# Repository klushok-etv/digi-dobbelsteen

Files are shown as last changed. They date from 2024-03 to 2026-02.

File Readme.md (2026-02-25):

# Digi Dobbelsteen

Digi Dobbelsteen is a digital dice project based on the attiny85 that uses 7 LEDs and a push button.

## Features

- 7 LEDs to display the result of the dice roll
- A push button to roll the dice
- A vibration sensor to roll the dice when the device is shaken

## Usage

The code was written in PlatformIO, so you can use that to compile and upload the code to the attiny85.

The schematic was made in KiCad 7.0, so you can use that to open the schematic and PCB files.

## Schematic

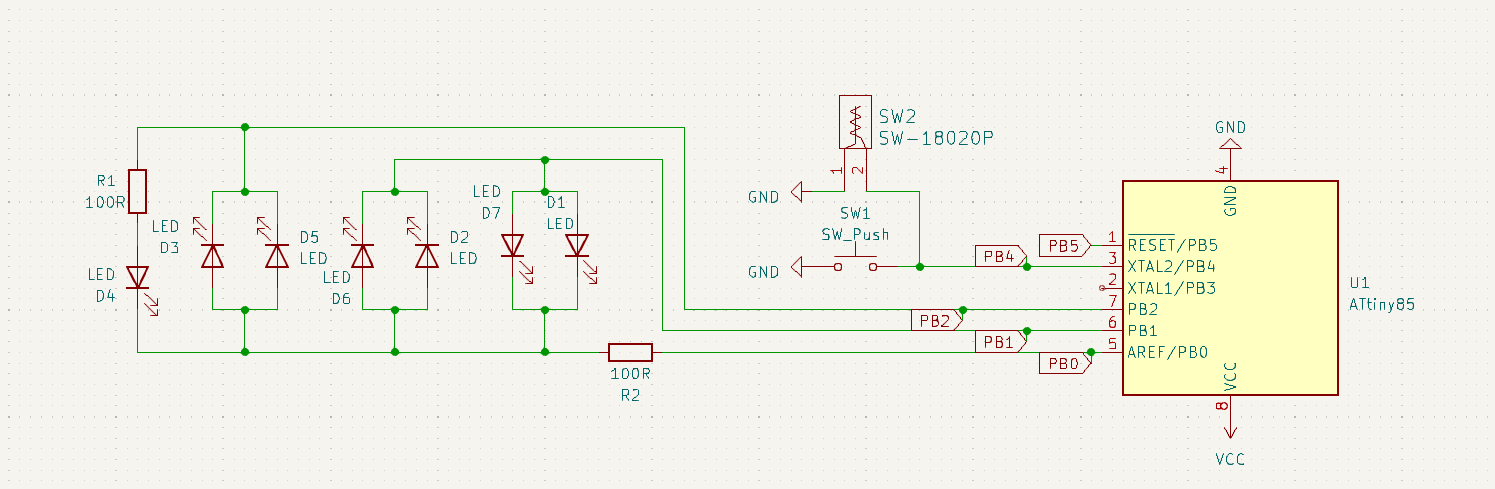
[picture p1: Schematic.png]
Schematic width=100px


## Charlieplexing

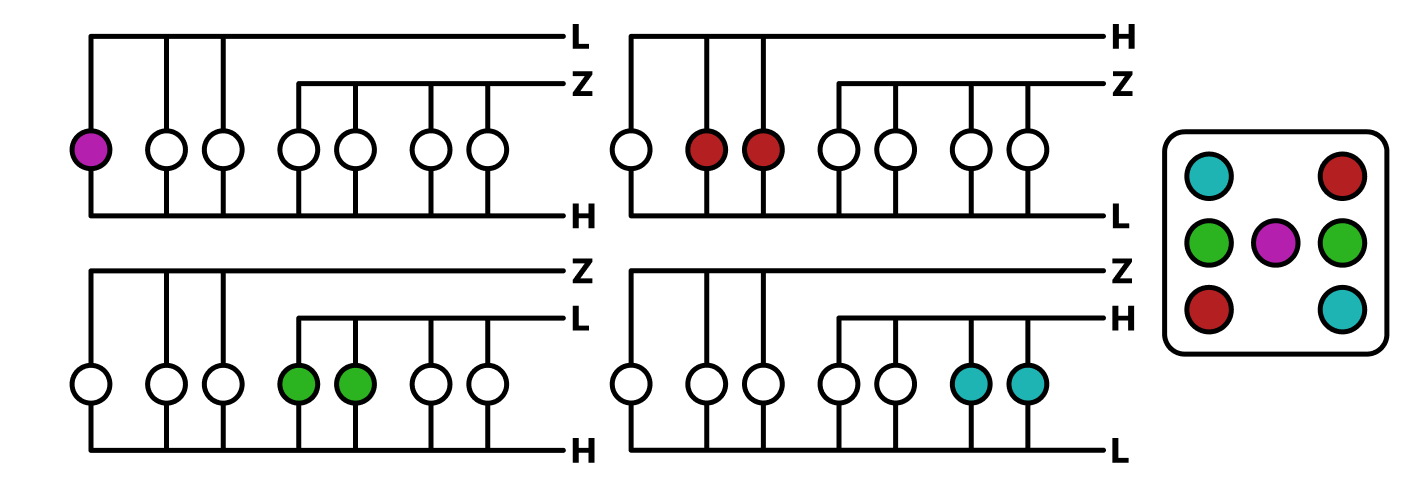
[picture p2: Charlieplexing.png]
Charlieplexing


## PCB

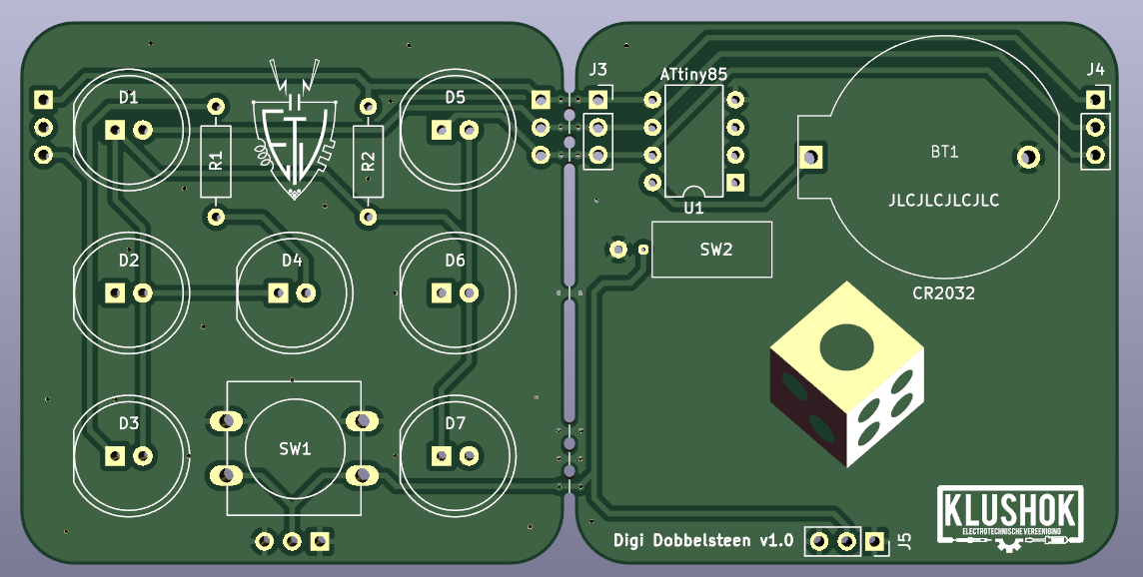
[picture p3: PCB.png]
PCB


## Programing

A precompiled binary is available for the attiny13 under releases. Upload to the chip using the following command:

```console
avrdude -p attiny13 -c usbasp-clone -B 100kHz -e -U flash:w:t13dobbelsteen.elf -U lfuse:w:t13dobbelsteen.elf -U hfuse:w:t13dobbelsteen.elf -U eeprom:w:t13dobbelsteen.elf -U lock:w:t13dobbelsteen.elf
```

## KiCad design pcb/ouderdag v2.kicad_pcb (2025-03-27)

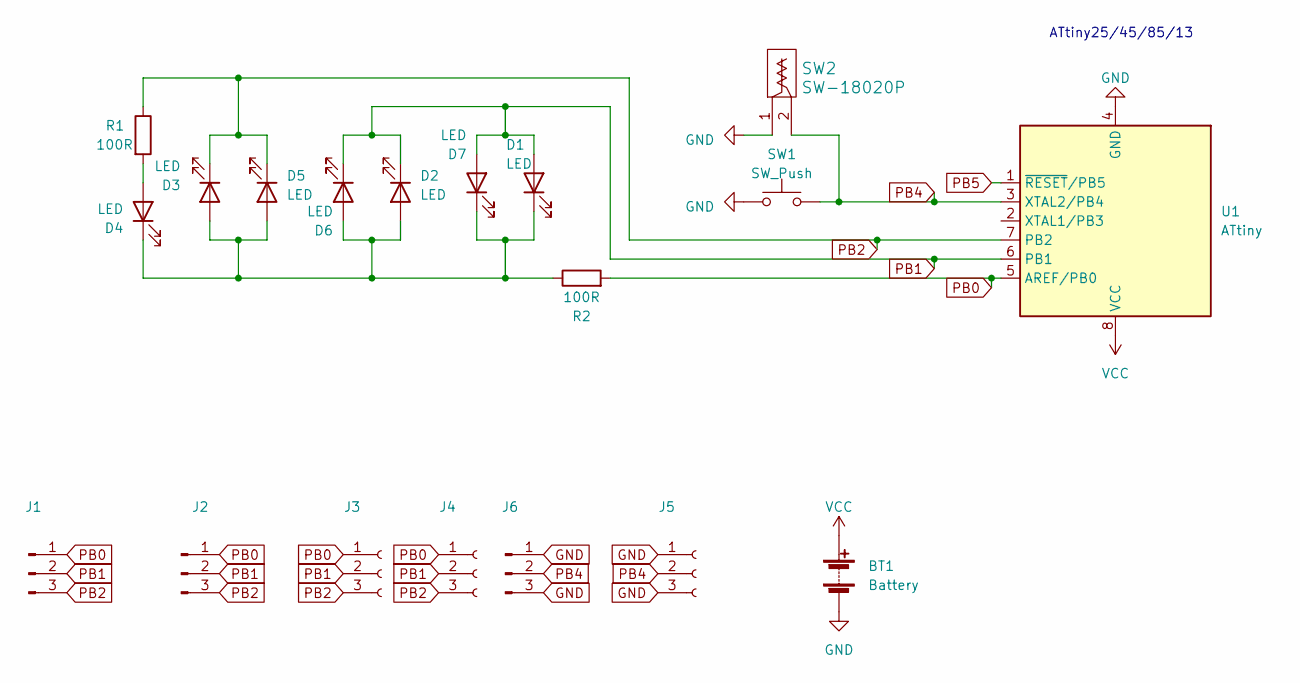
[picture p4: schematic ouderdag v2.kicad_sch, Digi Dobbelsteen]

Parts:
BT1: Battery; cr2032
D1, D2, D3, D4, D5, D6, D7: LED; LED_D10.0mm
J1, J2, J6: Conn_01x03_Pin; PinHeader_1x03_P2.54mm_Vertical
J3, J4, J5: Conn_01x03_Socket; PinSocket_1x03_P2.54mm_Vertical
R1, R2: 100R; R_Axial_DIN0207_L6.3mm_D2.5mm_P10.16mm_Horizontal
SW1: SW_Push; SW_PUSH-12mm
SW2: SW-18020P
U1: ATtiny; DIP-8_W7.62mm

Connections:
GND: BT1.2 (-), J5.1, J5.3, J6.1, J6.3, SW1.1, SW2.1, U1.4 (GND)
unnamed: D1.1 (K), D2.2 (A), D3.2 (A), D4.1 (K), D5.2 (A), D6.2 (A), D7.1 (K), R2.1
unnamed: D4.2 (A), R1.2
PB0: J1.1, J2.1, J3.1, J4.1, R2.2, U1.5 (AREF/PB0)
PB1: D1.2 (A), D2.1 (K), D6.1 (K), D7.2 (A), J1.2, J2.2, J3.2, J4.2, U1.6 (PB1)
PB2: D3.1 (K), D5.1 (K), J1.3, J2.3, J3.3, J4.3, R1.1, U1.7 (PB2)
PB4: J5.2, J6.2, SW1.2, SW2.2, U1.3 (XTAL2/PB4)
PB5: U1.1 (~RESET/PB5)
VCC: BT1.1 (+), U1.8 (VCC)

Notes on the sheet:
ATtiny25/45/85/13

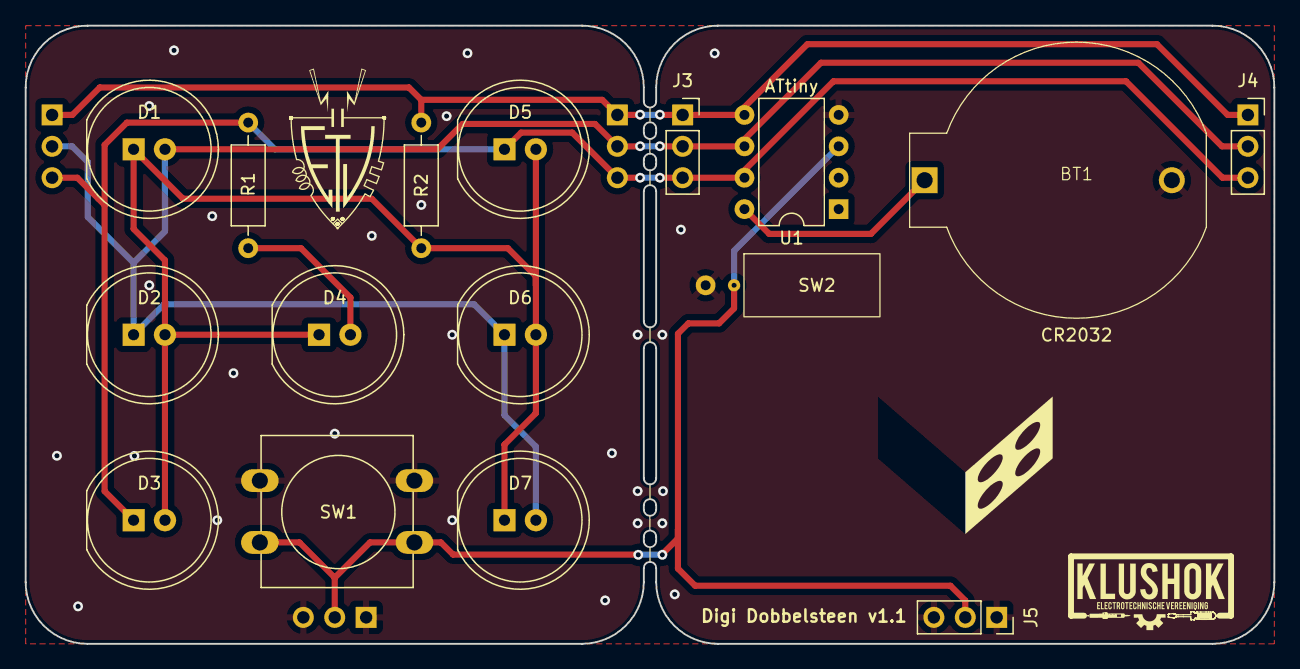
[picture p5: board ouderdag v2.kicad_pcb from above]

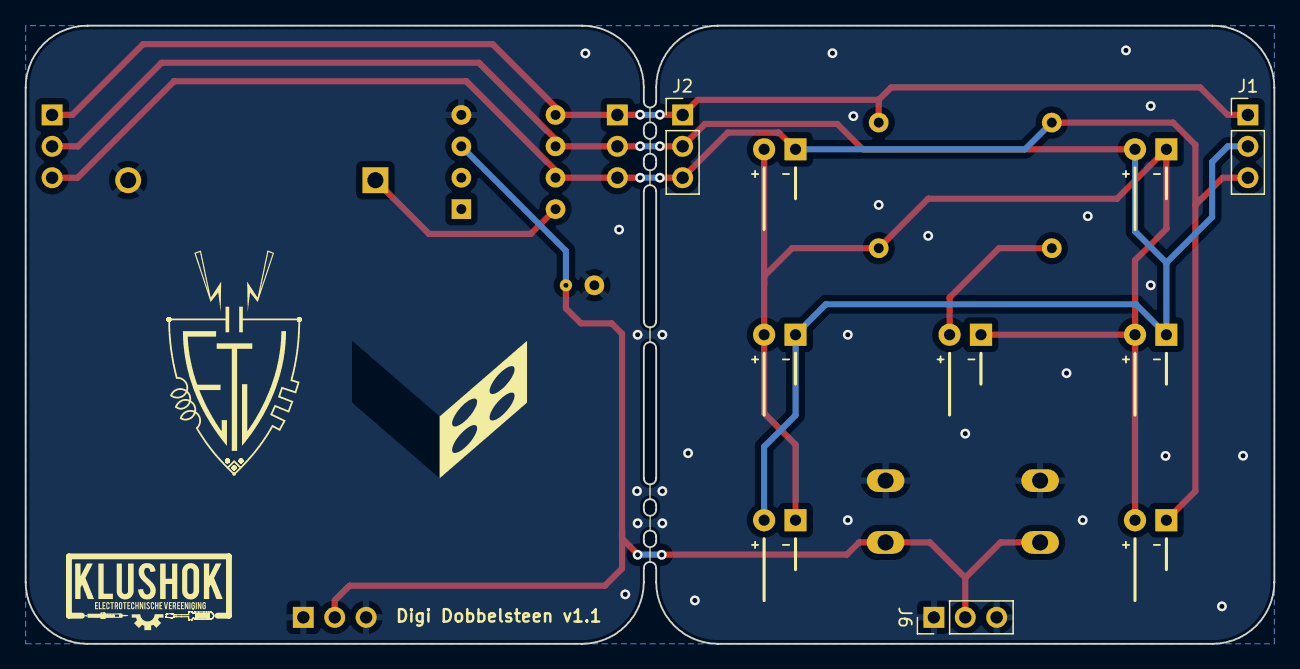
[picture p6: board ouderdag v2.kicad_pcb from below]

Board: 2 copper layers, 101.0 x 50.0 mm, 21 parts (4 on the bottom side), 8 nets.

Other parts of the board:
Ref**: Val**; Art
Ref**#2: Val**; Art

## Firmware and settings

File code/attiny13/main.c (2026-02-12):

/* Attiny Dice v1 using t13
   Jeremy de Waal - Electrotechnische Vereeniging - 2025
   sub 1k binary developed for use with attiny13
   Feature compatible with version from Ryan Kolk
*/

#include <avr/io.h>
#include <util/delay.h>
#include <avr/interrupt.h>
#include <avr/sleep.h>
#include <stdlib.h>
#include <avr/power.h>

/* function definitions */
uint8_t randomDieRoll();
void rngUpdate();
void auxRngUpdate();
void goToSleep ();
void displayRandomNumber();
void roll();
void setDelayLeft(uint16_t newDelay);
void myDelay(uint16_t delay);


/* Global Variables */
uint16_t rngState = 120;
uint8_t auxRngState = 4; // (VO)
enum CharlieState {STATE0, STATE1, STATE2};
enum CharlieState volatile charlieSlot = STATE0;
uint8_t ledOn, ledOff;
uint8_t const ledNumber[6] = {0b00000001, 0b00000010, 0b00000011, 0b00001010, 0b00001011, 0b00001110}; // lookup table
uint8_t volatile length, progress;
uint16_t volatile delayLeft;


int main(void)
{
    TCCR0B = (0 << CS02 | 0 << CS01 | 1 << CS00); // Timer/Counter0 run without prescaler
    TIMSK0 = (1 << TOIE0); // Timer/Counter0 Overflow Interrupt Enable
    PCMSK = (1 << PCINT4); // mask pin change interupt 4
    GIMSK = (1 << PCIE); // Pin Change Interrupt Enable
    sei(); // global interrupt enable
    while(1)
    {
        int16_t delayTime;
        roll(); // update global variables progress, length
        do // The animation part
        {
            displayRandomNumber();
            progress += 1;
            delayTime = 50 + (350 * progress / length); // could save some space if replaced by lookup table
            setDelayLeft((uint16_t)(0.001*F_CPU/256)*delayTime); // configure delay in ms
            while (delayLeft && progress) // check if delay as elapsed or progress has been reset
            {
                if (!(PINB & (1 << PIN4))) // keep doing as long as button is down
                {
                    // get some extra user randomness
                    auxRngUpdate();
                }
            }
        }
        while (progress < length);
        // the flashing part
        ledOff = ledOn; // store LED enable mask
        myDelay(0.3*F_CPU/256); // delay 300ms
        ledOn = 0;
        myDelay(0.3*F_CPU/256); // delay 300ms
        ledOn = ledOff;
        myDelay(0.3*F_CPU/256); // delay 300ms
        ledOn = 0;
        myDelay(0.3*F_CPU/256); // delay 300ms
        ledOn = ledOff;
        // non block delay for 1500ms
        progress = 1;
        setDelayLeft(1.5*F_CPU/256);
        while (delayLeft && progress);
        if (progress)  // skip sleep if interrupted
        {
            goToSleep();
        }
    }
    return 0;
}


ISR(TIM0_OVF_vect) // Timer overflow interrupt
{
    PORTB = (1 << PORTB4);
    uint8_t temp = 0;
    switch (charlieSlot){
    case STATE0:
        charlieSlot = STATE1;
        if (ledOn & 1 << 0)
        {
            temp = 1 << 0;
        }
        else if (ledOn & 1 << 1)
        {
            temp = 1 << 1;
        }
        break;
    case STATE1:
        charlieSlot = STATE2;
        if (ledOn & 1 << 2)
        {
            temp = 1 << 2;
        }
        if ((ledOn & 1 << 0) && (ledOn & 1 << 1)){
            temp = 1 << 1;
        }
        break;
    case STATE2:
    default: // this line saved 2 bytes
        charlieSlot = STATE0;
        if (ledOn & 1 << 3)
        {
            temp = 1 << 3;
        }
        break;
    }
    if (temp == 1 << 0)
    {
        DDRB = (1 << DDB2 | 1 << DDB0);
        PORTB = (1 << PORTB4 | 1 << PORTB2);
    }
    if (temp == 1 << 1)
    {
        DDRB = (1 << DDB0 | 1 << DDB2);
        PORTB = (1 << PORTB4 | 1 << PORTB0);
    }
    if (temp == 1 << 2)
    {
        DDRB = (1 << DDB0 | 1 << DDB1);
        PORTB = (1 << PORTB4 | 1 << PORTB0);
    }
    if (temp == 1 << 3)
    {
        DDRB = (1 << DDB1 | 1 << DDB0);
        PORTB = (1 << PORTB4 | 1 << PORTB1);
    }
    if (delayLeft){
        delayLeft--; // decrement the delay counter
    }
}

void displayRandomNumber() // set new LED enable mask
{
    // get random number 0-5
    // use lookup table to set leds
    ledOn = ledNumber[randomDieRoll()];
}

uint8_t randomDieRoll() // return a number in range 0-5
{
    uint8_t x;
    do
    {
        rngUpdate(); // update the LFSR a few times
        rngUpdate();
        rngUpdate();
        x = (rngState ^ auxRngState) & 0b111; // truncate number to 3 bits
    }
    while (x > 5); // try again if number is above 5
    return x;
}

void rngUpdate() // perform one iteration on the main LFSR
{
    rngState |= ((rngState << 15) ^ (rngState << 14)) & 1 << 15;
    rngState = (rngState >> 1);
}
void auxRngUpdate() // perform one iteration on the auxiliary LFSR
{
    auxRngState |= ((auxRngState << 6) ^ (auxRngState << 7)) & 1 << 7;
    auxRngState = (auxRngState >> 1);
}

void goToSleep () // sleep the mcu until button pressed
{
    TIMSK0 = (0 << TOIE0); // Timer/Counter0 Overflow Interrupt Disable
    DDRB = 0x00; // ensure all pins are input
    PORTB = 0xff; // set internal pull up to prevent floating pins (saves some power)
    set_sleep_mode(SLEEP_MODE_PWR_DOWN);
    do   // alternative for goto
    {
        sleep_enable();
        sleep_cpu();
        sleep_disable();
    }
    while(PINB & (1 << PIN4));

    TIMSK0 = (1 << TOIE0); // Timer/Counter0 Overflow Interrupt Enable
}

ISR (PCINT0_vect) // pin change Interrupt
{
    sleep_disable(); // exit sleep mode in case mcu was in sleep mode
    if (!(PINB & (1 << PIN4))) // check if button was pressed
    {
        roll(); // reset the global variables
    }
    rngUpdate(); // update LFSR for good measure
}

void roll() // sets amount of numbers to show and clears progress
{
    length = 6 + randomDieRoll() + randomDieRoll(); // generate some number 6 to 16
    progress = 0; // clear progress
}

void setDelayLeft(uint16_t newDelay) // safe way to acces variable
{
    cli();
    delayLeft = newDelay; // set new value
    sei();
}

void myDelay(uint16_t delay) // delay based on Timer/Counter0
{
    setDelayLeft(delay); // configure delay duration
    while (delayLeft); // stall until the timer interrupt has decremented this to zero
}

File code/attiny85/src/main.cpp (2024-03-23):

/* Attiny Dice v1
  Ryan Kolk - Electrotechnische Vereeniging - 2024
  ATtiny85 @ 1 MHz (internal oscillator; BOD disabled)
   
  CC BY 4.0
  Licensed under a Creative Commons Attribution 4.0 International license: 
  http://creativecommons.org/licenses/by/4.0/

  Atmet Attiny  pinout
                   +-\/-+
  Ain0 (D 5) PB5  1|    |8  Vcc
  Ain3 (D 3) PB3  2|    |7  PB2 (D 2) Ain1
  Ain2 (D 4) PB4  3|    |6  PB1 (D 1) pwm1
             GND  4|    |5  PB0 (D 0) pwm0
                   +----+
*/

#include <Arduino.h>
#include <avr/sleep.h>    // Sleep Modes
#include <avr/power.h>    // Power management

void goToSleep ();

int animateRolling();
void nonBlockingDelay(int ms);
void flashNumber(int num);
void displayNumber(int num);
//Initial brightness levels for the rows
bool Level[4] = {0,0,0,0};
const uint8_t animation[4] = {1,2,3,2};

//Matrix to map numbers 1-6 to the correct leds
const bool Number[6][4] = {
  {1,0,0,0},
  {0,1,0,0},
  {1,1,0,0},
  {0,1,0,1},
  {1,1,0,1},
  {0,1,1,1},
};
bool interrupt = false;
bool awake = true;
static uint8_t row, ramp;

ISR (PCINT0_vect)        // Interrupt service routine 
{
  MCUCR&=~(1<<SE);      //Disabling sleep mode inside interrupt routine
  if(awake && digitalRead(PB4) == LOW){
    interrupt=true;
  }
}


// Timer overflow interrupt
ISR(TIM1_COMPA_vect) {
  static uint8_t dir, out;
    row = (row + 1) & 0x03;
    if(row == 0){
      dir=0b101;
      out=0b100;
    } else if(row == 1){
      dir=0b101;
      out=0b001;
    } else if(row == 2){
      dir=0b011;
      out=0b001;
    } else if(row == 3){
      dir=0b011;
      out=0b010;
    }
  if (Level[row] == 0){            // Turn off LED if brightness is 0
    out = 0b000;
    dir=0b000;
  }
  
  DDRB = (DDRB & 0xF8) | dir;         // Set Pin direction. 1 is output, 0 is input (High impedance)
  PORTB = (PORTB & 0xF8) | out;       // Set Pin. 1 is high, 0 is low
}

void setup() {
  // if(F_CPU == 8000000) clock_prescale_set(clock_div_1); // Set clock to 8MHz
  clock_prescale_set(clock_div_8); // Set clock to 1MHz

  // Set up Timer/Counter1 to contol the LEDs
  TCCR1 = 1<<CTC1 | 1<<CS10;          // Divide by 2
  GTCCR = 0;                          // No PWM
  OCR1A = 0;
  OCR1C = 125-1;                      // 16kHz
  TIMSK = TIMSK | 1<<OCIE1A;          // Compare Match A interrupt

  //Setup sleep with interrupt on PB4
  pinMode (PB4, INPUT);     
  digitalWrite (PB4, HIGH);           // Set internal pullup
  PCMSK  |= bit (PCINT4);             // interrupt on PB4
  GIFR   |= bit (PCIF);               // Clear any outstanding interrupts
  GIMSK  |= bit (PCIE);               // Enable pin change interrupts 
  GIMSK |= (1 << PCIE);
  int randomness = analogRead(PB3);// Get a bit of randomness from analog pin that is not being used
  randomSeed(randomness);    // Set seed for the random number generator
}
void loop () {
  int number = animateRolling();

  delay(300);
  flashNumber(number);
  interrupt=false;
  nonBlockingDelay(1500);
  if(interrupt){
    interrupt = false;
    return;
  }
  goToSleep();
  
}

int animateRolling(){
  int randomNumber = 0;
  int length = random(6,15);
  for(int i=0; i<length; i++){
    randomNumber = random(0,6);
    displayNumber(randomNumber);
    nonBlockingDelay(50 + (i * 350 / length));
    if(interrupt){
      length = random(6,15);
      i=0;
      interrupt = false;
      delay(50);
    }
  }
  return randomNumber;
}

void nonBlockingDelay(int ms) {
  for(int i=0; i<ms; i++){
    delay(1);
    if(interrupt)
     return;
  }
  return;
}

void flashNumber(int num){
  for(int i=0; i<2; i++){
    displayNumber(num);
    delay(400);

    displayNumber(-1);
    delay(400);
  }
  displayNumber(num);
}

void displayNumber(int num){
  if(num == -1){
    for(int i=0; i<4; i++){
      Level[i] = 0;
    }
  } else {
    for(int i=0; i<4; i++){
      Level[i] = Number[num][i];
    }
  }
  
}

void goToSleep () {
  for(int i=0; i<4; i++){
    Level[i] = 0;
  }
  MCUCR|=(1<<SM1);      // Enabling sleep mode and powerdown sleep mode
  MCUCR|= (1<<SE);     //Enabling sleep enable bit
  DDRB = (DDRB & 0xF8) | 0b000;
  PORTB = (PORTB & 0xF8) | 0b000;
  delay(10);
  ramp=0;
  row=0;
  awake = false;
  backtosleep: 
  set_sleep_mode(SLEEP_MODE_PWR_DOWN);
  ADCSRA = 0;                         // turn off ADC
  power_all_disable ();               // power off ADC, Timer 0 and 1, serial interface
  sleep_enable();
  sei();  
  sleep_cpu();   
  cli();                            
  sleep_disable();  
  sei();       
  power_all_enable();                 // power everything back on
  if(digitalRead(PB4) == HIGH){
    goto backtosleep;
  }
  awake = true;
}

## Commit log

2024-03-22 updated code and pcb
    [ouderdag v2.kicad_pcb, ouderdag v2.kicad_sch]
2025-03-27 change to generic ATtiny
    PCB changes:
    version 1.0 -> version 1.1
    ATtiny85 -> ATtiny
    mousebite trace FFF -> FBF
    removed order number
    [ouderdag v2.kicad_pcb, ouderdag v2.kicad_sch]
